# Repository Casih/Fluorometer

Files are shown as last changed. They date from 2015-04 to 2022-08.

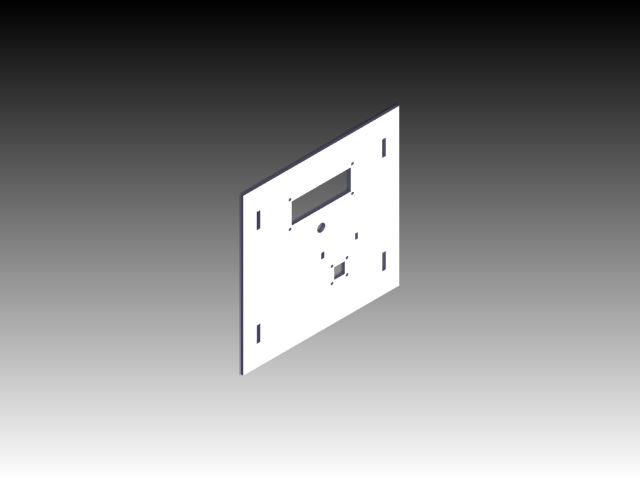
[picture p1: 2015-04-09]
Cuvette/Imagen3.jpg

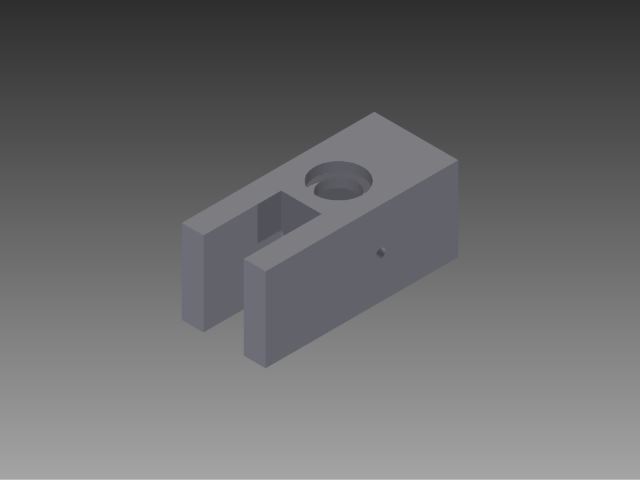
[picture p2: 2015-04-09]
Cuvette/Imagen.jpg

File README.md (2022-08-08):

# Flourometer

This repository contains everything related to the construction of a fluorometer, using a TCS230 color sensor.

*****INSTRUCTIONS*****

1. Plug The machine to a USB port, or a 9V batery or a 9 to 12 V wall adapter.
  - The machine should now be on the mode selection screen
  
2. Push the button to select which mode you wish to operate in

3. Follow onscreen instructions.

*****REMEMBER*****

1. Modes in this machine are cyclical so if you for some reason messed up in some part of the procedure just press enter until you are in the end of the mode, after that simply choose a new mode with the buttons.

*****WHAT NOT TO DO*****

1. Please do not plug it into the wall using a USB phone adapter since the voltage supplied might be to low and the fluorometer might stop working (In previous experiences we had to re upload the code to the arduino when we did this, so this probably erased the code in it).

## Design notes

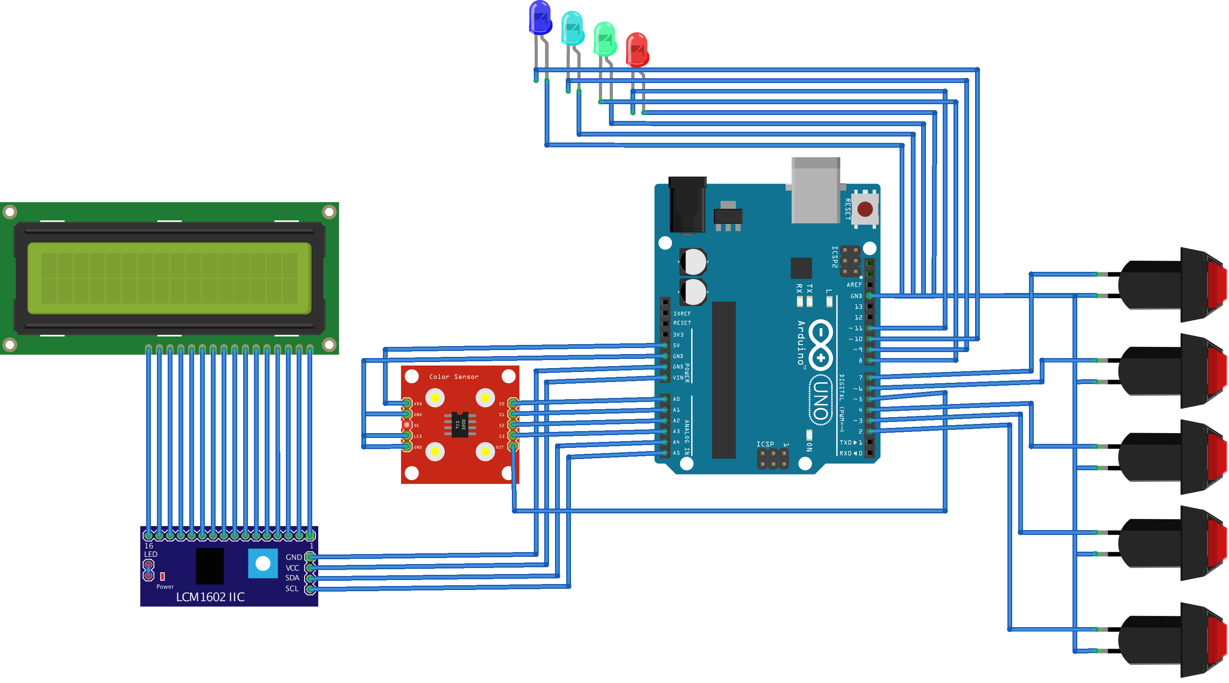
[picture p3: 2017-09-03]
Circuit/Fluorometer.png

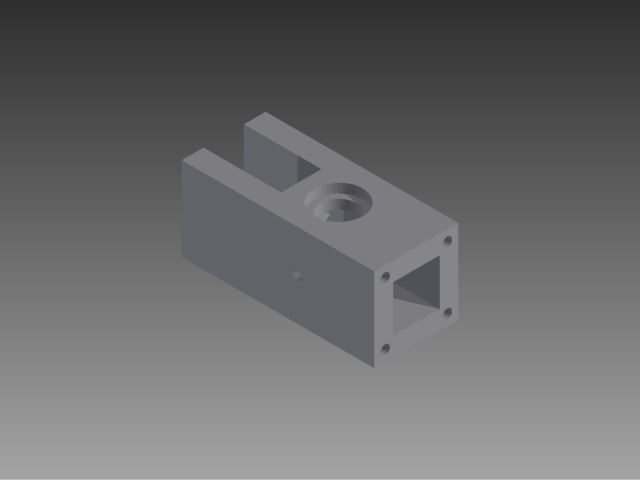
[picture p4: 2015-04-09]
Cuvette/Imagen2.jpg

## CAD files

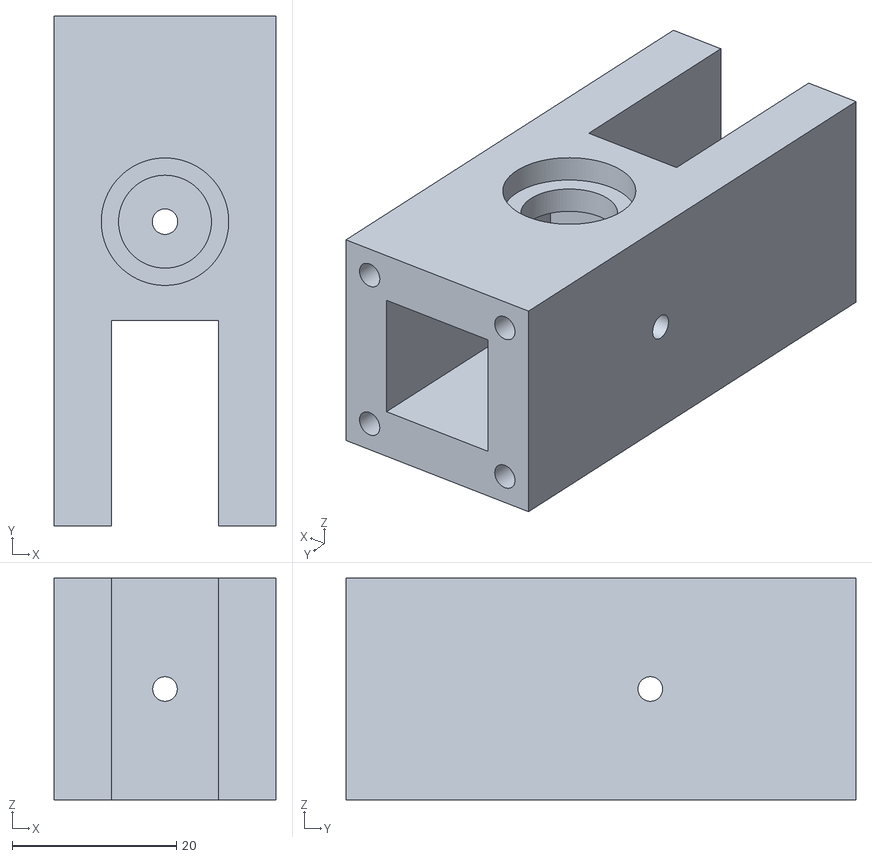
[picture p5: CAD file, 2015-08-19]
Cuvette/Cubetaimpresion.stl
27.0 x 62.0 x 27.0

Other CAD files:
Cuvette/Cubeta Final.dwg
Cuvette/Cubeta Final.ipt
Cuvette/Impresion Final.skp

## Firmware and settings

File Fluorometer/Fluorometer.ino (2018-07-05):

#include <LiquidCrystal_I2C.h>
#include <Wire.h>
#include <FreqCount.h>
#include <math.h>

LiquidCrystal_I2C lcd(0x27,16,2);
float Blank;
float Measurement;
float Bl_OD;   //Blank OD
float OD_Fin;
int Modo = 0;
int Color = 0;
//Pin button definitions
const int red = 2;     // the number of the pushbutton pin red mode
const int green = 3;    // the number of the pushbutton pin green mode
const int blue = 4;     // the number of the pushbutton pin blue mode
const int OD = 6;       // the number of the pushbutton pin optical density mode
const int Enter = 7;    // the number of the pushbutton pin Enter
int ModoR = HIGH;
int ModoV = HIGH;
int ModoA = HIGH;
int ModoOD = HIGH;
int ModoEn = HIGH;
//LED pin definition
const int RL = 8;     // the number of the lED pin red mode
const int GL= 9;    // the number of the LED pin green mode
const int BL= 10;     // the number of the LED pin bluemode
const int ODL = 11;       // the number of the LED pin optical density mode
//***********************************************************************
int i;

void setup() {
  Serial.begin(9600);        // initialize serial communication:
  FreqCount.begin(1000);     //  //initialize frequency counter:
  // initialize the LED pins Sensor:
  pinMode(5, INPUT);         // Frequency reader
  pinMode(A0, OUTPUT);       // S0
  pinMode(A1, OUTPUT);       // S1
  pinMode(A2, OUTPUT);       // S2
  pinMode(A3, OUTPUT);       // S3
  //********LED's colors********
  pinMode(RL,OUTPUT);          //red
  pinMode(GL,OUTPUT);          //green
  pinMode(BL,OUTPUT);         //blue
  pinMode(ODL,OUTPUT);         //od
  digitalWrite(RL, LOW);    //
  digitalWrite(GL, LOW);    //
  digitalWrite(BL, LOW);    //
  digitalWrite(ODL, LOW);    //
  // Sensor off:
  digitalWrite(A0, HIGH);    //
  digitalWrite(A1, HIGH);    //
  //Button initialization
  pinMode(red, INPUT);
  pinMode(blue, INPUT);
  pinMode(green, INPUT);
  pinMode(OD, INPUT);
  pinMode(Enter, INPUT);
  int i = 0;
  // LCD screen setup
  lcd.init();                // 
  lcd.backlight();           //
  lcd.clear();               // 
  lcd.setCursor(0,0);        //
  lcd.print("Select mode:");  //
  lcd.setCursor(0,1);        //
  lcd.print("r, g ,c, OD");   //

  Serial.println("Blank,Measurement,Mode"); 
}

void loop() {
  ModoR = digitalRead(red);
  ModoV = digitalRead(green);
  ModoA = digitalRead(blue);
  ModoOD = digitalRead(OD);
  ModoEn = digitalRead(Enter);
  if (ModoR == LOW) {
    i=1;
    }
  if (ModoV == LOW) {
    i=2;
    }
  if (ModoA == LOW) {
    i=3;
    }
  if (ModoOD == LOW) {
    i=4;
    }
  if (ModoEn == LOW){
    i=5;
  }
// Cases
 switch (i) {
      case 1:
        Modo=1;
        rojo();
        i=0;
        break;
      case 2:
        Modo=1;
        verde();
        i=0;
        break;
      case 3:
        Modo=1;
        bluel();
        i=0;
        break;
      case 4:
        Modo=1;
        ODD();
        i=0;
        break;
      case 5:
        if(Modo==2){
          color();
          i=0;
        }
        break;
      default:
        break;
    }
  delay(100);
}

void color(){
  //Serial.println("color");
  switch (Color) {
    case 1:  
      rojo2();
      break;
    case 2:  
      verde2();
      break;
    case 3:  
      blue2();
      break;
    case 4:  
      OD2();
      break;
    default:
    break;
   }
}

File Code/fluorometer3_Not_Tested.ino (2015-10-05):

#include <LiquidCrystal_I2C.h>
#include <Wire.h>
#include <FreqCount.h>
#include <math.h>

LiquidCrystal_I2C lcd(0x27,16,2);
unsigned long count;
unsigned long count2;
double count0;
double count1;
double printvar;
const int buttonPin = 2;    // the number of the pushbutton pin
const int ledPin = 13;      // the number of the LED pin
int i;
int inByte;
// Variables will change:
int ledState = HIGH;         // the current state of the output pin
int buttonState;             // the current reading from the input pin
int lastButtonState = LOW;   // the previous reading from the input pin

// the following variables are long's because the time, measured in miliseconds,
// will quickly become a bigger number than can be stored in an int.
long lastDebounceTime = 0;  // the last time the output pin was toggled
long debounceDelay = 50;    // the debounce time; increase if the output flickers

void setup() {
  // initialize serial communication:
  Serial.begin(9600);        //
  
  //initialize frequency counter:
  FreqCount.begin(1000);     // 
  
  // initialize the LED pins:
  pinMode(5, INPUT);         // LECTOR DE FRECUENCIA
  pinMode(A0, OUTPUT);       // S0
  pinMode(A1, OUTPUT);       // S1
  pinMode(A2, OUTPUT);       // S2
  pinMode(A3, OUTPUT);       // S3
  pinMode(6,OUTPUT);
  pinMode(9,OUTPUT);
  pinMode(10,OUTPUT);
  pinMode(11,OUTPUT);
  
  // Sensor en apagado:
  digitalWrite(A0, HIGH);    //
  digitalWrite(A1, HIGH);    //
  
  // initialize lcd screen
  
  lcd.init();                //
  lcd.backlight();           //
  lcd.clear();               // 
  lcd.setCursor(0,0);        //
  lcd.print("Seleccione:");  //
  lcd.setCursor(0,1);        //
  lcd.print("R, G, C, O");   //
  
  pinMode(buttonPin, INPUT);
  pinMode(ledPin, OUTPUT);
  int i = 0;
}
void mostrarR()
{
  if(FreqCount.available()){
          count = FreqCount.read();
          lcd.clear();  
          lcd.setCursor(0,0);
          lcd.print("listo preparese");
          lcd.setCursor(0,1);
          lcd.print("a insertar Muestra");
          delay(3000);
          lcd.clear();  
          lcd.setCursor(0,0);       
          lcd.print("Insertar muestra");
          lcd.setCursor(0,1);
          lcd.print("Tiene 8 segundos");
          delay(8000);
          count2 = FreqCount.read();
          lcd.clear();
          lcd.setCursor(0,0);
          lcd.print("Red:");
          lcd.setCursor(0,1);
          lcd.print(count2 - count);
          Serial.println(count2 - count);
        }
}
void mostrarV()
{
  if(FreqCount.available()){
          count = FreqCount.read();
          lcd.clear();  
          lcd.setCursor(0,0);
          lcd.print("listo preparese");
          lcd.setCursor(0,1);
          lcd.print("a insertar Muestra");
          delay(3000);
          lcd.clear();  
          lcd.setCursor(0,0);       
          lcd.print("Insertar muestra");
          lcd.setCursor(0,1);
          lcd.print("Tiene 8 segundos");
          delay(8000);
          count2 = FreqCount.read();
          lcd.clear();
          lcd.setCursor(0,0);
          lcd.print("Green:");
          lcd.setCursor(0,1);
          lcd.print(count2 - count);
          Serial.println(count2 - count);
        }
}
void mostrarA()
{
  if(FreqCount.available()){
          count = FreqCount.read();
          lcd.clear();  
          lcd.setCursor(0,0);
          lcd.print("listo preparese");
          lcd.setCursor(0,1);
          lcd.print("a insertar Muestra");
          delay(3000);
          lcd.clear();  
          lcd.setCursor(0,0);       
          lcd.print("Insertar muestra");
          lcd.setCursor(0,1);
          lcd.print("Tiene 8 segundos");
          delay(8000);
          count2 = FreqCount.read();
          lcd.clear();
          lcd.setCursor(0,0);
          lcd.print("Cyan:");
          lcd.setCursor(0,1);
          lcd.print(count2 - count);
          Serial.println(count2 - count);
        }
}
void mostrarod()
{
  if(FreqCount.available()){
        delay(8000);
        count0 = FreqCount.read();
        lcd.clear();  
        lcd.setCursor(0,0);
        lcd.print("listo preparese");
        lcd.setCursor(0,1);
        lcd.print("a insertar Muestra");
        delay(3000);
        lcd.clear();  
        lcd.setCursor(0,0);       
        lcd.print("Insertar muestra");
        lcd.setCursor(0,1);
        lcd.print("Tiene 8 segundos");
        delay(8000);
        count1 = FreqCount.read();
        printvar = - log10(count1/count0);
        lcd.clear(); 
        lcd.setCursor(0,0);
        lcd.print("Optical Density:");
        lcd.setCursor(0,1);
        lcd.print(printvar);
        Serial.println(printvar);
   }
}
void rojo()
{
  lcd.clear();
  digitalWrite(A2, LOW);
  digitalWrite(A3, LOW);
  digitalWrite(6, HIGH);
  digitalWrite(9, LOW);
  digitalWrite(10, LOW);
  digitalWrite(11, LOW);
  lcd.setCursor(0,0);
  lcd.print("Rojo:");
  delay(2000);
  lcd.clear();
  lcd.setCursor(0,0);
  lcd.print("Inserte Blanco");
  mostrarR();
  //delay(4000);
}
void verde()
{
  lcd.clear();
  digitalWrite(A2, HIGH);
  digitalWrite(A3, HIGH);
  digitalWrite(9, HIGH);
  digitalWrite(6, LOW);
  digitalWrite(10, LOW);
  digitalWrite(11, LOW);
  lcd.setCursor(0,0);
  lcd.print("Verde:");
  delay(2000);
  lcd.clear();
  lcd.setCursor(0,0);
  lcd.print("Inserte Blanco");
  mostrarV();
  //delay(4000);      
}
void azul()
{
  lcd.clear();
  digitalWrite(A2, LOW);
  digitalWrite(A3, HIGH);
  digitalWrite(10, HIGH);  
  digitalWrite(9, LOW);
  digitalWrite(6, LOW);
  digitalWrite(11, LOW);
  lcd.setCursor(0,0);
  lcd.print("Cyan:");
  delay(2000);
  lcd.clear();
  lcd.setCursor(0,0);
  lcd.print("Inserte Blanco");
  mostrarA();
  //delay(4000);
}
void OD()
{
  lcd.clear();
  digitalWrite(A2, HIGH);
  digitalWrite(A3, LOW);
  digitalWrite(11, HIGH);
  digitalWrite(9, LOW);
  digitalWrite(10, LOW);
  digitalWrite(6, LOW);
  lcd.setCursor(0,0);
  lcd.print("Densidad Optica");
  delay(2000);
  lcd.clear();
  lcd.setCursor(0,0);
  lcd.print("Insertar blanco");
  lcd.setCursor(0,1);
  lcd.print("Tiene 8 segundos");
  mostrarod();
  //delay(4000);
}
void def()
{
  lcd.clear();
  lcd.setCursor(0,0);
  lcd.print("Seleccione:");
  digitalWrite(6,LOW);
  digitalWrite(9, LOW);
  digitalWrite(10, LOW);
  digitalWrite(11, LOW);
  lcd.setCursor(0,1);
  lcd.print("R, G, C, O");
}
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

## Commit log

2015-04-09 Included LED programming
2015-08-19 Updated information and designs
    [Cubeta Final impresion.dwg, Cubeta Final sin huecos.dwg, Cubeta Final sin huecos.ipt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]
2015-10-05 fluorometer3 provides the means for the machine to "Blank" fluorescent samples, not justo only OD simples anymore
